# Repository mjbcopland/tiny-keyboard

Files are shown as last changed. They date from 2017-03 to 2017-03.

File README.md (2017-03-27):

# Tiny Keyboard

Design files and example code for my ATtiny85 1-key keyboard.

1-key keyboard

&nbsp;

## Related links

* **[V-USB](https://www.obdev.at/products/vusb/index.html)**  
  Software USB communication for AVR

* **[Micronucleus](https://github.com/micronucleus/micronucleus)**  
  Bootloader and tools used to program the keyboard

* **[DigistumpArduino](https://github.com/digistump/DigistumpArduino)**  
  ATtiny85 support for the Arduino IDE

* **[r/MechanicalKeyboards](https://www.reddit.com/r/MechanicalKeyboards/)**  
  For more keyboard science

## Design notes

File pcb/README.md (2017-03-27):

<https://oshpark.com/shared_projects/BiJILe6J>

PCB Top PCB Bottom

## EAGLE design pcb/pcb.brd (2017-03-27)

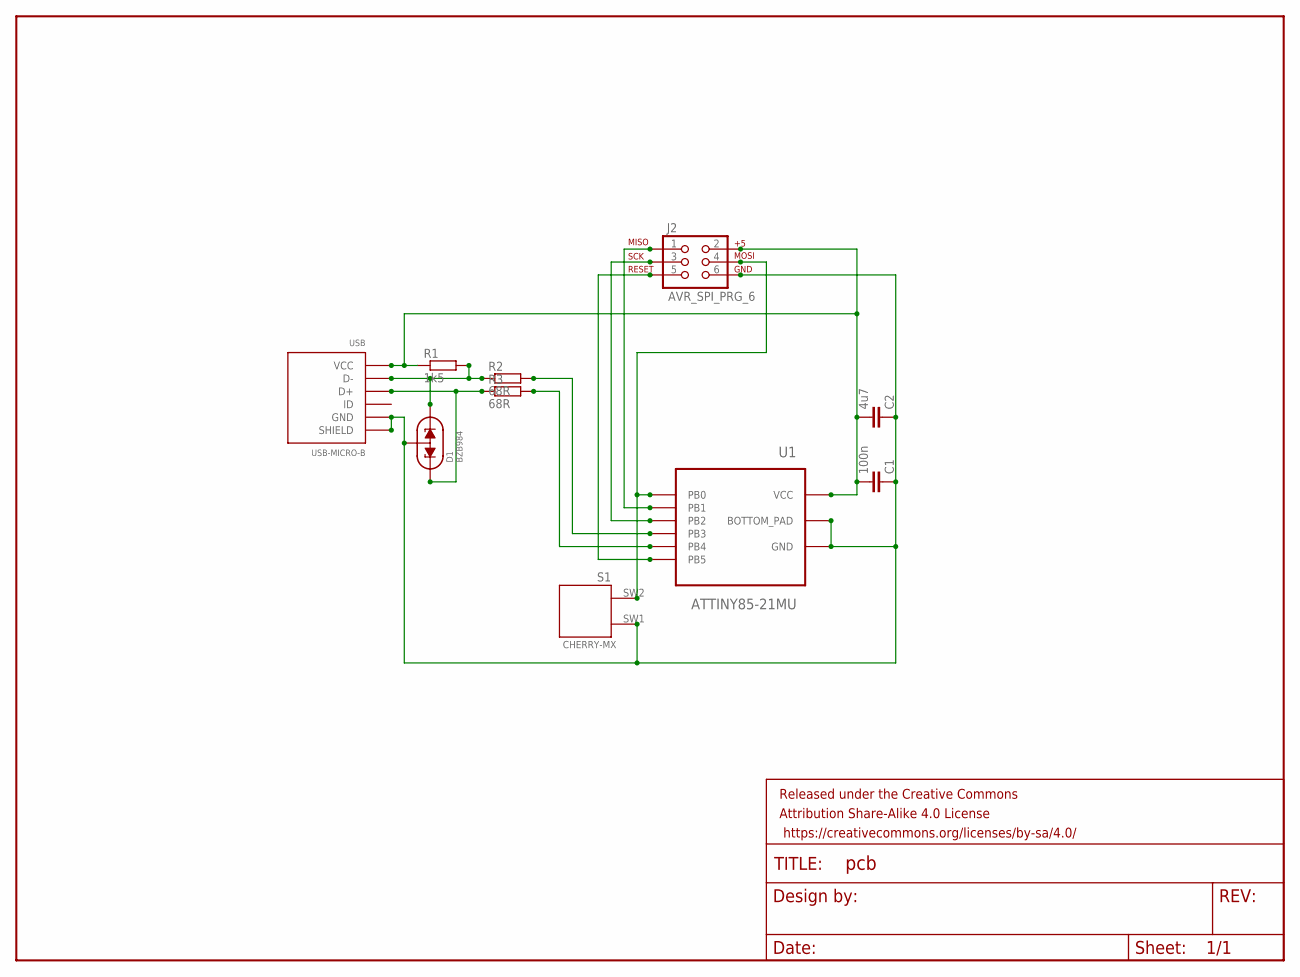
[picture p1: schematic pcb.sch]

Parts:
C1: 100n; C0603
C2: 4u7; C0603
D1: BZB984; SOT663
FRAME1: FRAME-LETTERNO_PACKAGE; DUMMY
J2: AVR_SPI_PRG_6; 2X3_PADS
R1: 1k5; R0603
R2, R3: 68R; R0603
S1: CHERRY-MX-PLATE
U1: ATTINY85-21MU; QFN-20-4MM
USB: USB-MICRO-B; MICRO-USB-B

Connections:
D+: R3.2, U1.5 (PB4)
D-: R2.2, U1.2 (PB3)
GND: C1.1, C2.1, D1.3 (ANODE), J2.6, S1.SW1 (PIN-1), U1.8 (GND), U1.21 (BOTTOM_PAD), USB.5 (GND), USB.P$1 (SHIELD), USB.P$2 (SHIELD), USB.P$3 (SHIELD), USB.P$4 (SHIELD), USB.SHIELD1 (SHIELD), USB.SHIELD2 (SHIELD), USB.SHIELD3 (SHIELD), USB.SHIELD3A (SHIELD), USB.SHIELD4 (SHIELD), USB.SHIELD5 (SHIELD), USB.SHIELD6 (SHIELD), USB.SHIELD6A (SHIELD)
unnamed: J2.1, U1.12 (PB1)
unnamed: J2.4, S1.SW2 (PIN-2), U1.11 (PB0)
unnamed: J2.3, U1.14 (PB2)
unnamed: D1.2 (CATHODE2), R1.2, R2.1, USB.2 (D-)
unnamed: D1.1 (CATHODE1), R3.1, USB.3 (D+)
unnamed: C1.2, C2.2, J2.2, R1.1, U1.15 (VCC), USB.1 (VCC)
unnamed: J2.5, U1.1 (PB5)

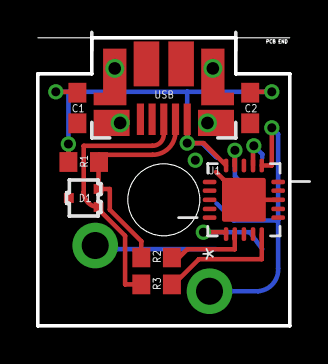
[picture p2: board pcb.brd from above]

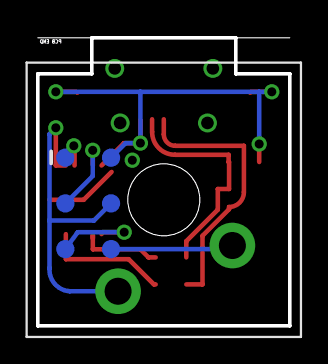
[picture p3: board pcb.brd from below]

Board: 2 copper layers, 14.0 x 16.0 mm, 11 parts (2 on the bottom side), 10 nets.

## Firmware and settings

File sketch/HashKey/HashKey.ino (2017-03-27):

#include <Button.h> // https://github.com/mjbcopland/Button
#include <DigiKeyboard.h>

Button button(0, INTERNAL_PULLUP, 25);

void setup() {
  
}

void loop() {
  button.update();
  DigiKeyboard.update();

  if (button.wasPressed()) {
    DigiKeyboard.sendKeyPress(0x32); // Keyboard Non-US # and ~
  }
  else if (button.wasReleased()) {
    DigiKeyboard.sendKeyPress(NULL);
  }
}

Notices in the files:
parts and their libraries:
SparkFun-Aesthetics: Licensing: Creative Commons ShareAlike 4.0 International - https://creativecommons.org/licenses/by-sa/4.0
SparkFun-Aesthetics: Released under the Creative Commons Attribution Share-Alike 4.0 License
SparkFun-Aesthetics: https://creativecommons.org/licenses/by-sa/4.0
